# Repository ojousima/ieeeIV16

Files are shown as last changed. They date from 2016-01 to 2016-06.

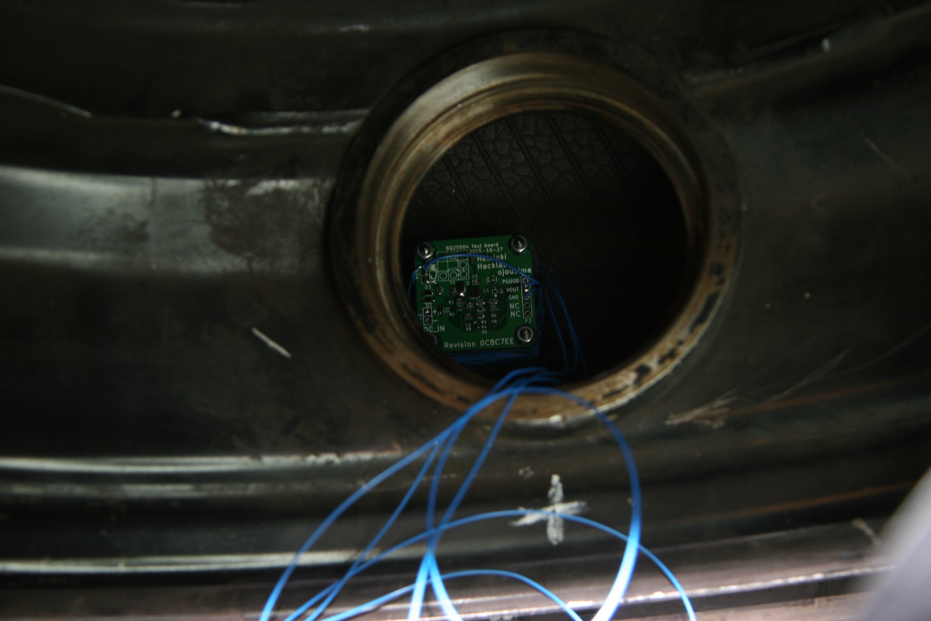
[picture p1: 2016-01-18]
images/harvester_mounted.jpg

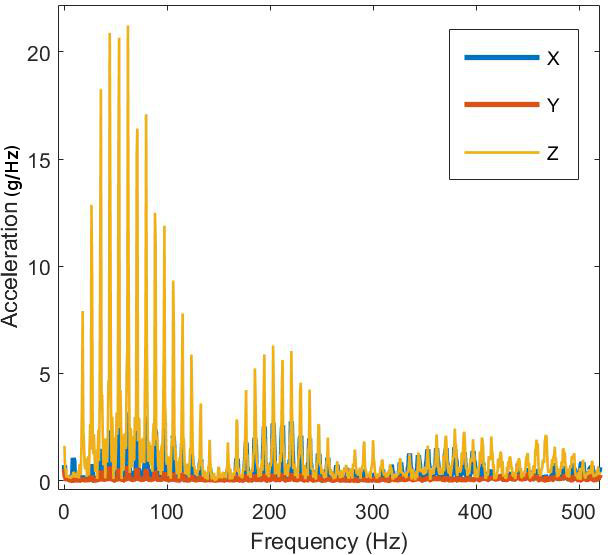
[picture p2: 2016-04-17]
images/fft.png

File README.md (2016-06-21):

# ieeeIV16
Design materials and measurement results for [IV16](http://iv2016.org/) conference paper Energy Harvesting System for Intelligent Tyre Sensors. I will add link to conference paper itself once the paper is available.

You might also be interested in my [Master's Thesis](https://github.com/ojousima/thesis) which has a lot broader information about the subject of energy harvesting in tyres.

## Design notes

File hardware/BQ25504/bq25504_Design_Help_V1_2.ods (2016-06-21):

User Input | VBIAS | 1.25 | V
Fixed
 | Comparator threshold for VSTOR maximum. |  |  |  |  | Comparator threshold voltages indicating when |  |  |  |  | Comparator threshold for VSTOR minimum. |  |  |  |  | Maximum power point threshold, e.g. ~0.7-0.8 of
 | Typically the max storage element voltage, |  |  |  |  | VSTOR has risen above VBAT_OK_HYS or fallen |  |  |  |  | Typically the min storage element voltage, |  |  |  |  | solar panel's open circuit voltage
 | e.g. 4.2V for LiIon battery |  |  |  |  | below VBAT_OK |  |  |  |  | e.g. 2.5V for LiIon battery
 | 2.5V < VBAT_OV < 5.25V |  |  |  |  | VBAT_OV > VBAT_OK_HYST > VBAT_UV |  |  |  |  | 2.2V < VBAT_UV < VBAT_OV |  |  |  |  | MPPT
Desired |  |  |  |  |  | RSUM1 | 10 | Mohm |  |  |  |  |  |  |  | RSUM1 | 10 | Mohm
Desired | RSUM1 | 10 | Mohm |  |  | VBAT_OK | 2.4 | V | > VBAT_UV |  | RSUM1 | 10 | Mohm |  |  | VIN_DC(OC) | 1 | V | Open Circuit Volts
Desired | VBAT_OV | 3.5 | V |  |  | VBAT_OK_HYST | 2.9 | V | > VBAT_OK |  | VBAT_UV | 2.2 | V |  |  | VREF_SAMP | 0.8 | V | MPP voltage
 |  |  |  |  |  |  |  | closest 1% resistor1 |  |  |  |  |  |  |  |  |  | closest 1% resistor1
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

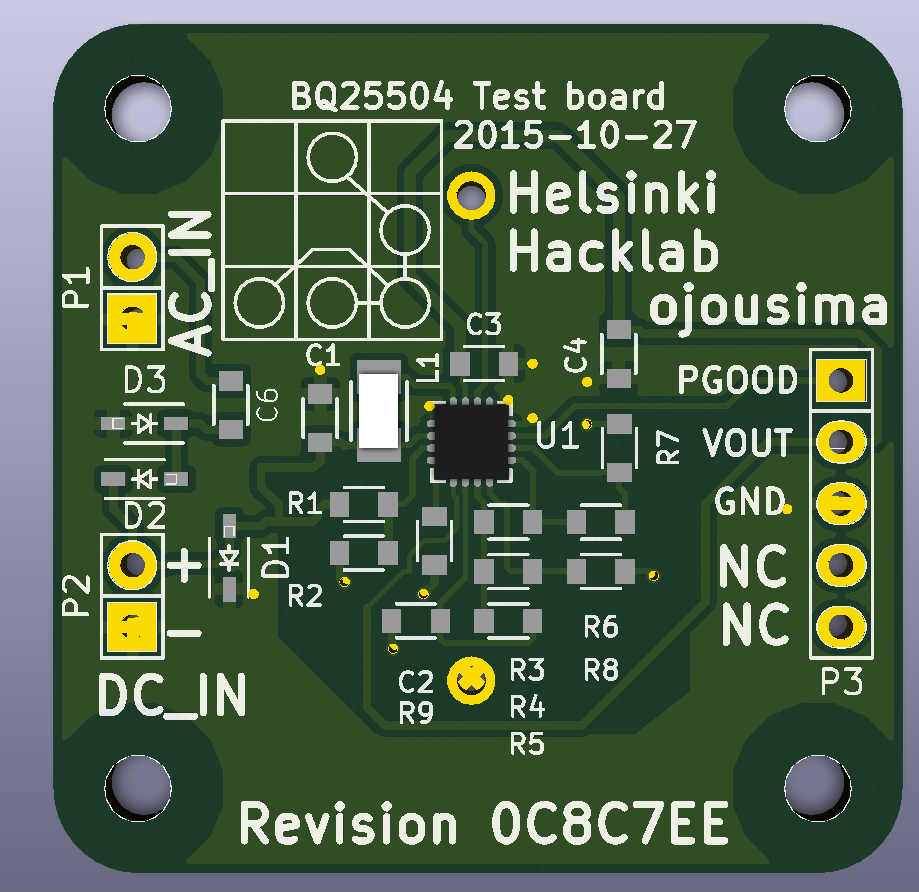
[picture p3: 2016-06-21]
hardware/BQ25504/gerber/picture.PNG

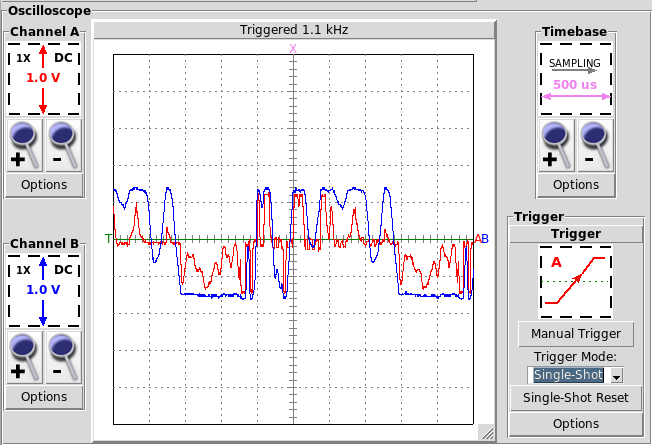
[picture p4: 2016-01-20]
images/piezo_td_vi_2.png

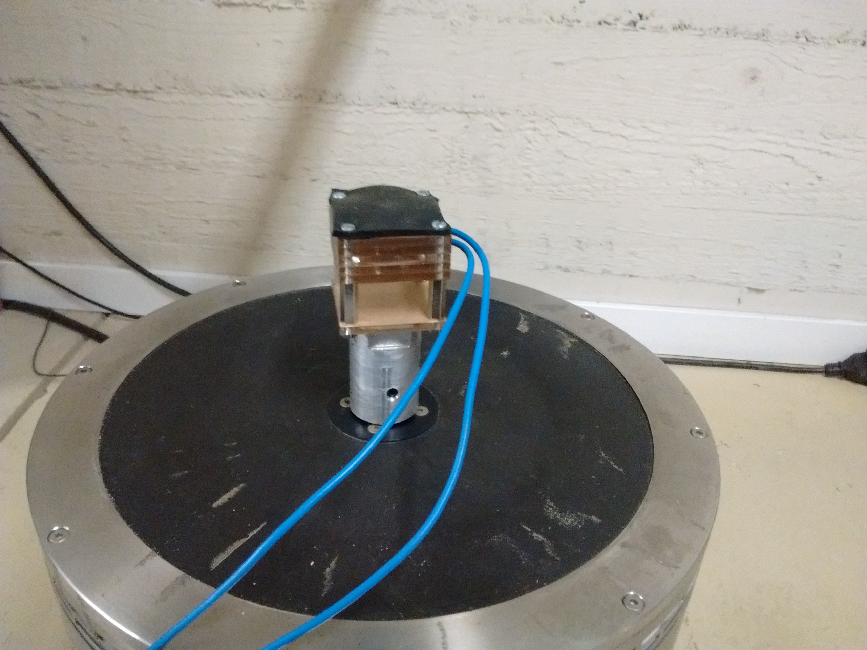
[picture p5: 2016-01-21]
images/piezo_shaker.jpg

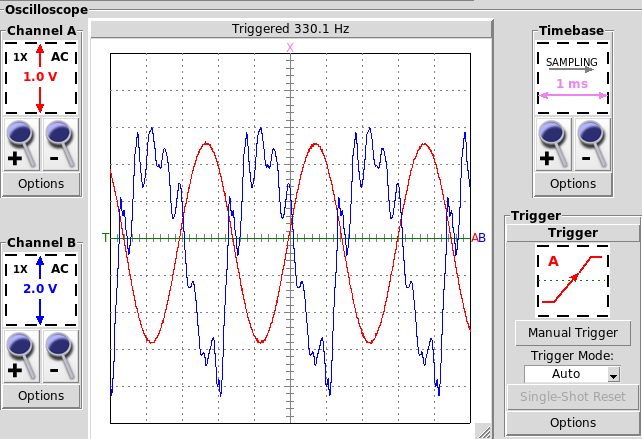
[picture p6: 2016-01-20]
images/piezo_td_12k_330hz_2_2.png

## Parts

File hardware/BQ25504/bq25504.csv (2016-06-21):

Id | Designator | Package | Quantity | Designation | Supplier and ref
1 | NC1,NC2,NC3,NC4 | m2.5_mechanical_npth_mount | 4 | Mounting_hole
2 | C1,C4,C6 | SMD0603_A | 3 | 10u | %
3 | C2 | SMD0603_A | 1 | 10n | %
4 | C3 | SMD0603_A | 1 | 100n | %
5 | C5 | EECRG0V155HN | 1 | EECRG0V155(V|H)N | %
6 | L1 | SMD1206_A | 1 | INDUCTOR_SMALL | %
7 | P1,P2 | Pin_Header_Straight_1x02 | 2 | CONN_01X02
8 | R1 | SMD0603_A | 1 | 4M | %
9 | R2 | SMD0603_A | 1 | 6M | %
10 | R3 | SMD0603_A | 1 | 1M8 | %
11 | R4 | SMD0603_A | 1 | 1M
12 | R5 | SMD0603_A | 1 | 4M22 | %
13 | R6 | SMD0603_A | 1 | 2M5 | %
14 | R7 | SMD0603_A | 1 | 5M6 | %
15 | R8 | SMD0603_A | 1 | 9M | %
16 | R9 | SMD0603_A | 1 | 5M62 | %
17 | U1 | QFN-16-1EP_3x3mm_Pitch0.5mm | 1 | BQ25504
18 | D1,5V1 | SOD-323-A | 2 | TVS | %
19 | P3 | Pin_Header_Straight_1x05 | 1 | CONN_01X03
20 | D2,D3 | SOD-323-A | 2 | D_Schottky | %

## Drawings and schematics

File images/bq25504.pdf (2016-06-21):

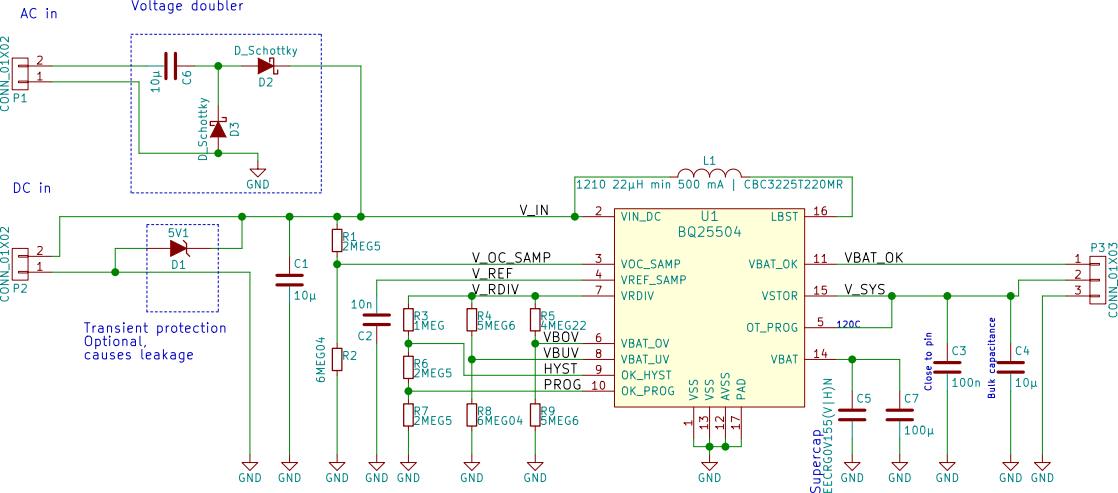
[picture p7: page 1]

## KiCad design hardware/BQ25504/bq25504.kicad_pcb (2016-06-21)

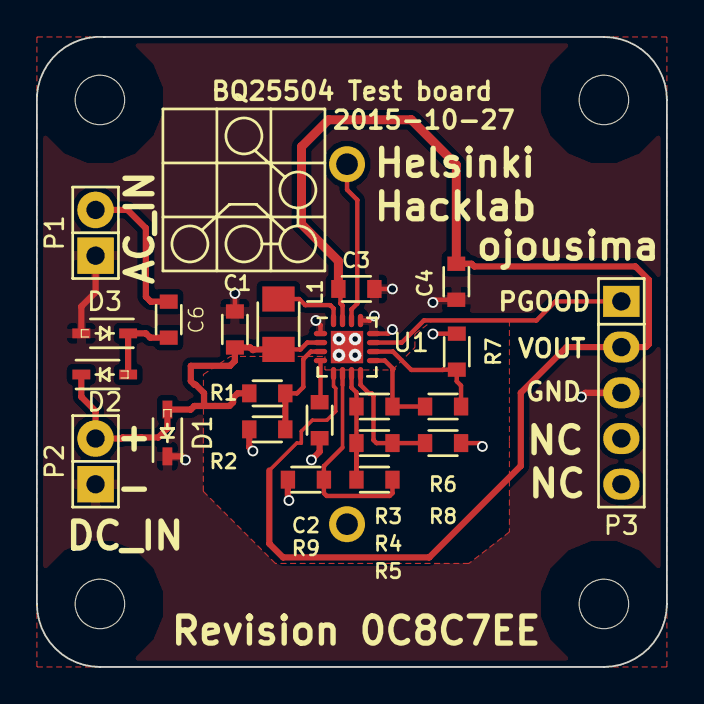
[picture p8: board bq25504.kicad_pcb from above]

Board: 2 copper layers, 35.0 x 35.0 mm, 27 parts (1 on the bottom side), 15 nets.

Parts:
C1, C2, C3, C4, C6: C; SMD0603_A
C5: EECRG0V155(V|H)N; EECRG0V155HN
D1: TVS; SOD-323-A
D2, D3: D_Schottky; SOD-323-A
L1: INDUCTOR_SMALL; SMD1206_A
NC1, NC2, NC3, NC4: Mounting_hole; m2.5_mechanical_npth_mount
P1, P2: CONN_01X02; Pin_Header_Straight_1x02
P3: CONN_01X03; Pin_Header_Straight_1x05
R1, R2, R3, R4, R5, R6, R7, R8, R9: R_Small; SMD0603_A
U1: BQ25504; QFN-16-1EP_3x3mm_Pitch0.5mm

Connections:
/HYST: R3.2, R6.1, U1.9
/PROG: R6.2, R7.1, U1.10
/VBAT_OK: P3.1, U1.11
/VBOV: R5.2, R9.1, U1.6
/VBUV: R4.2, R8.1, U1.8
/V_IN: C1.1, D1.2, D2.1, L1.1, P2.2, R1.1, U1.2
/V_OC_SAMP: R1.2, R2.1, U1.3
/V_RDIV: R3.1, R4.1, R5.1, U1.7
/V_REF: C2.2, U1.4
/V_SYS: C3.1, C4.1, P3.2, U1.5, U1.15
GND: C1.2, C2.1, C3.2, C4.2, C5.2, D1.1, D3.2, P1.1, P2.1, P3.3, R2.2, R7.2, R8.2, R9.2, U1.1, U1.12, U1.13, U1.17
unnamed: C5.1, U1.14
unnamed: C6.1, D2.2, D3.1
unnamed: C6.2, P1.2
unnamed: L1.2, U1.16

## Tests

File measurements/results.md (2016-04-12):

#Measurements on dynamometer
Date of measurements was 2016-04-08. Raw data is available in .zip in .tdms format.

##Results
###Performance testing
Load, Velocity, voltages, and temperature were measured. Power is calculated by change of energy in capacitor in time of measurement.

Load | Velocity  | V0       | Vt       | Temp   | dTemp | Power  | Time   | test # 
-----|-----------|----------|----------|--------|-------|--------|--------|---------
0 kN | 00 km / h | 3.0510 V | 3.0470 V | N/A    | N/A   | -28 µW | 10 min | 1
1 kN | 10 km / h | 3.0365 V | 3.0345 V | 21.6 C | N/A   | -14 µW | 10 min | 2
1 kN | 20 km / h | 3.0336 V | 3.0326 V | 24.0 C | 1.1 C | -7  µW | 10 min | 4
1 kN | 30 km / h | 3.0306 V | 3.0296 V | 26.2 C | 0.5 C | -7  µW | 10 min | 7
1 kN | 40 km / h | 3.0229 V | 3.0214 V | 28.3 C | -0.7C | -10 µW | 10 min | 11
2 kN | 10 km / h | 3.0345 V | 3.0336 V | 22.9 C | 1.3 C | -6  µW | 10 min | 3
2 kN | 20 km / h | 3.0310 V | 3.0306 V | 25.7 C | 1.7 C | -3  µW | 10 min | 6
2 kN | 30 km / h | 3.0267 V | 3.0255 V | 27.2 C | 0.3 C | -8  µW | 10 min | 9
2 kN | 40 km / h | 3.0214 V | 3.0208 V | 29.5 C | 1.2 C | -4  µW | 10 min | 12
3 kN | 10 km / h | 3.0325 V | 3.0311 V | 24.0 C | 0.0 C | -10 µW | 10 min | 5
3 kN | 20 km / h | 3.0282 V | 3.0271 V | 26.9 C | 0.7 C | -8  µW | 10 min | 8
3 kN | 30 km / h | 3.0222 V | 3.0229 V | 29.0 C | 1.8 C | +5  µW | 10 min | 10
3 kN | 40 km / h | 3.0208 V | 3.0223 V | 30.8 C | 1.3 C | +13 µW |  8 min | 13
0 kN | 00 km / h | 3.0217 V | 3.0178 V | N/A    | N/A   | -27 µW | 10 min | 14

###Endurance testing
Device was driven at 60 km / h at kN and 4 kN loads. Raw data is in endurance.zip in .tdms format.
Device broke down quickly at 4 kN load, no useful data was obtained.

Load | Velocity  | V0       | Vt       | Temp   | dTemp | Power  | Time   | test # 
-----|-----------|----------|----------|--------|-------|--------|--------|---------
0 kN | 00 km / h | 3.0360 V | 3.0330 V | 24.0C  | N/A   | -21 µW | 10 min | 1
2 kN | 60 km / h | 3.0330 V | 3.0456 V | 29.6C  | 5.6 C | +88 µW | 10 min | 2

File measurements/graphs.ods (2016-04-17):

Load | Velocity | V0 | Vt | Temp | dTemp | Power | Time | test #
0 | 0 | 3.051 | 3.047 |  |  | -28 | 10 | 1
0 | 0 | 3.0217 | 3.0178 |  |  | -27 | 10 | 14
1 | 10 | 3.0365 | 3.0345 | 21.6 |  | -14 | 10 | 2
1 | 20 | 3.0336 | 3.0326 | 24 | 1.1 | -7 | 10 | 4
1 | 30 | 3.0306 | 3.0296 | 26.2 | 0.5 | -7 | 10 | 7
1 | 40 | 3.0229 | 3.0214 | 28.3 | -0.7 | -10 | 10 | 11
2 | 10 | 3.0345 | 3.0336 | 22.9 | 1.3 | -6 | 10 | 3
2 | 20 | 3.031 | 3.0306 | 25.7 | 1.7 | -3 | 10 | 6
2 | 30 | 3.0267 | 3.0255 | 27.2 | 0.3 | -8 | 10 | 9
2 | 40 | 3.0214 | 3.0208 | 29.5 | 1.2 | -4 | 10 | 12
3 | 10 | 3.0325 | 3.0311 | 24 | 0 | -10 | 10 | 5
3 | 20 | 3.0282 | 3.0271 | 26.9 | 0.7 | -8 | 10 | 8
3 | 30 | 3.0222 | 3.0229 | 29 | 1.8 | 5 | 10 | 10
3 | 40 | 3.0208 | 3.0223 | 30.8 | 1.3 | 13 | 8 | 13
Velocity | V0 | Vt | Temp | dTemp | Power | Time | test #
0 | 3.051 | 3.047 |  |  | -28 | 10 | 1
0 | 3.0217 | 3.0178 |  |  | -27 | 10 | 14
10 | 3.0365 | 3.0345 | 21.6 |  | -14 | 10 | 2
10 | 3.0345 | 3.0336 | 22.9 | 1.3 | -6 | 10 | 3
10 | 3.0325 | 3.0311 | 24 | 0 | -10 | 10 | 5
20 | 3.0336 | 3.0326 | 24 | 1.1 | -7 | 10 | 4
20 | 3.031 | 3.0306 | 25.7 | 1.7 | -3 | 10 | 6
20 | 3.0282 | 3.0271 | 26.9 | 0.7 | -8 | 10 | 8
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

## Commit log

2016-01-21 Use lighter colours for mounting dwg
2016-01-21 Add figure of tyre deformation
2016-04-12 Add key figures and graphs of measurements
    [graphs.ods]
2016-04-17 Add final results, convert images to png
    [graphs.ods]
2016-06-21 Add circuitry design files
    [bq25504.csv, bq25504.kicad_pcb, bq25504.sch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]
2016-06-21 Add gerbers
    [bq25504-B_Cu.gbl, bq25504-B_Mask.gbs, bq25504-B_SilkS.gbo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]
